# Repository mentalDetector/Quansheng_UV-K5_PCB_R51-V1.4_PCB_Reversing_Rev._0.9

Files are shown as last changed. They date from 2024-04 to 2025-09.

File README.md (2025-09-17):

# Quansheng UV-K5 Hardware Reverse Engineering Project

## Introduction

This project aims to reverse-engineer the hardware design of the Quansheng UV-K5 handheld amateur radio transceiver, specifically focusing on V1.4 of the PCB, which is also used in UV-K5(8) and similar models. The goal was to create a KiCad design that closely resembles the original hardware. Feel free to use this KiCad project to explore more about the mentioned radio or as a starting point for enhancing Quansheng's original design, such as improving RF filtering.

## Thanks!

This project is a community effort, and many people have contributed in various ways (e.g., suggesting make and model of previously unidentified hardware components, component measurements, 3D model creation, reviews, hardware donations, etc.). I particularly want to thank Manuel ([Manuel's GitHub](https://github.com/manujedi)) for donating the PCB and measuring components, and Ludwich ([Ludwich's GitHub](https://github.com/ludwich66)) for thorough documentation (including maintaining the wiki) and improving my initial schematic.

## The Process

Manuel desoldered all components from his PCB after his radio malfunctioned and began measuring them. For components he couldn't measure, he sent them along with his PCB to me.

I measured the remaining components using a nanoVNA, soldering each to a test board to ensure precise measurements.

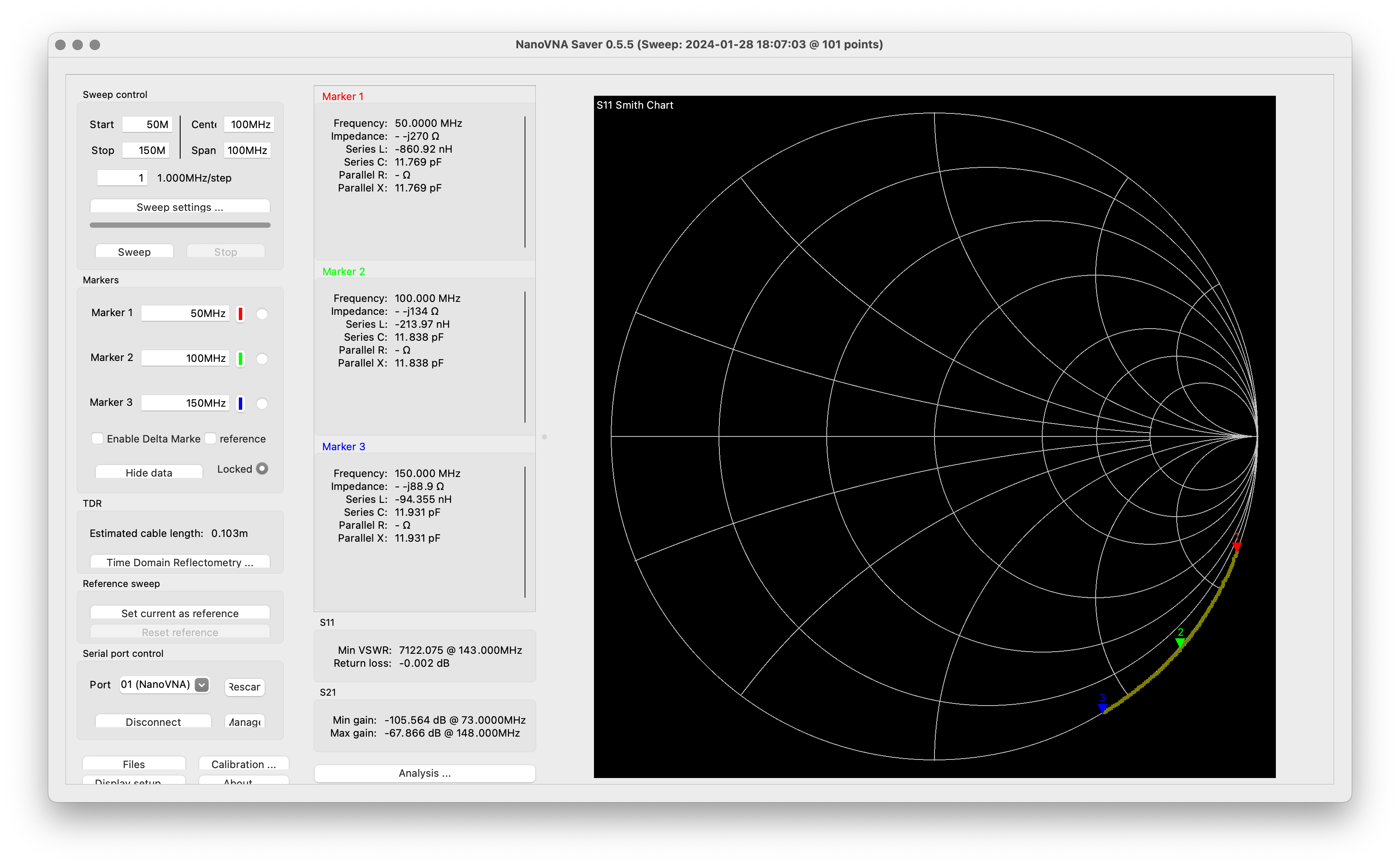
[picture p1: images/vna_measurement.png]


All documentation is available here: [Parts](https://github.com/ludwich66/Quansheng_UV-K5_Wiki/wiki/Parts---Teile). This resource was invaluable during the reverse engineering process.

While we might have encountered measurement errors and may not have chosen the correct component values every time, overall, I believe we've done a decent job. If you spot an error, please inform Ludwich or me.

Afterward, I photographed the PCB to obtain high-resolution images. I also sanded down the PCB to expose the two inner layers, documenting the process here: [PCB Layer Preparation](https://github.com/mentalDetector/Quansheng_UV-K5_PCB_R51-V1.4).

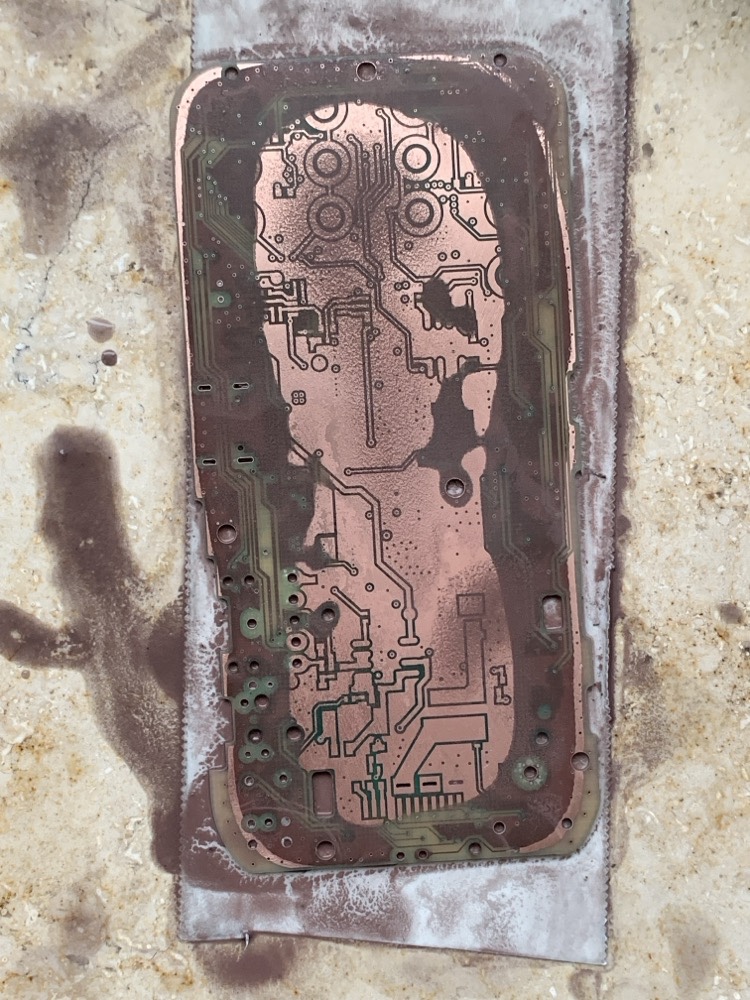
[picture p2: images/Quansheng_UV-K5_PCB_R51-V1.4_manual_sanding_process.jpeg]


I then processed the layer pictures, imported them into the KiCad PCB editor, and aligned everything as accurately as possible. You can still find these pictures in the PCB editor for reference, contributing to the project's size (approximately 60 MB).

Next came the laborious tasks:
- Setting up the PCB view with all PCB borders
- Selecting a random component on the PCB picture
- Placing it onto the schematic
- Switching to the PCB editor and placing the component
- Checking the 3D view of the PCB
- Linking a 3D model for the component if necessary (a time-consuming task)
- Placing additional components
- Connecting the components in the schematics editor
- Switching to the PCB view, updating it
- Running DRC on the schematics and PCB and correcting gating issues

All of my work was completed over a period of about three months, mostly on weekends.

## The Results

<a href="https://github.com/mentalDetector/Quansheng_UV-K5_PCB_R51-V1.4_PCB_Reversing_Rev._0.9/blob/main/images/Quansheng_UV-K5_PCB_R51-V1.4_Rev_0.9_Schematic.pdf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" target="_blank">
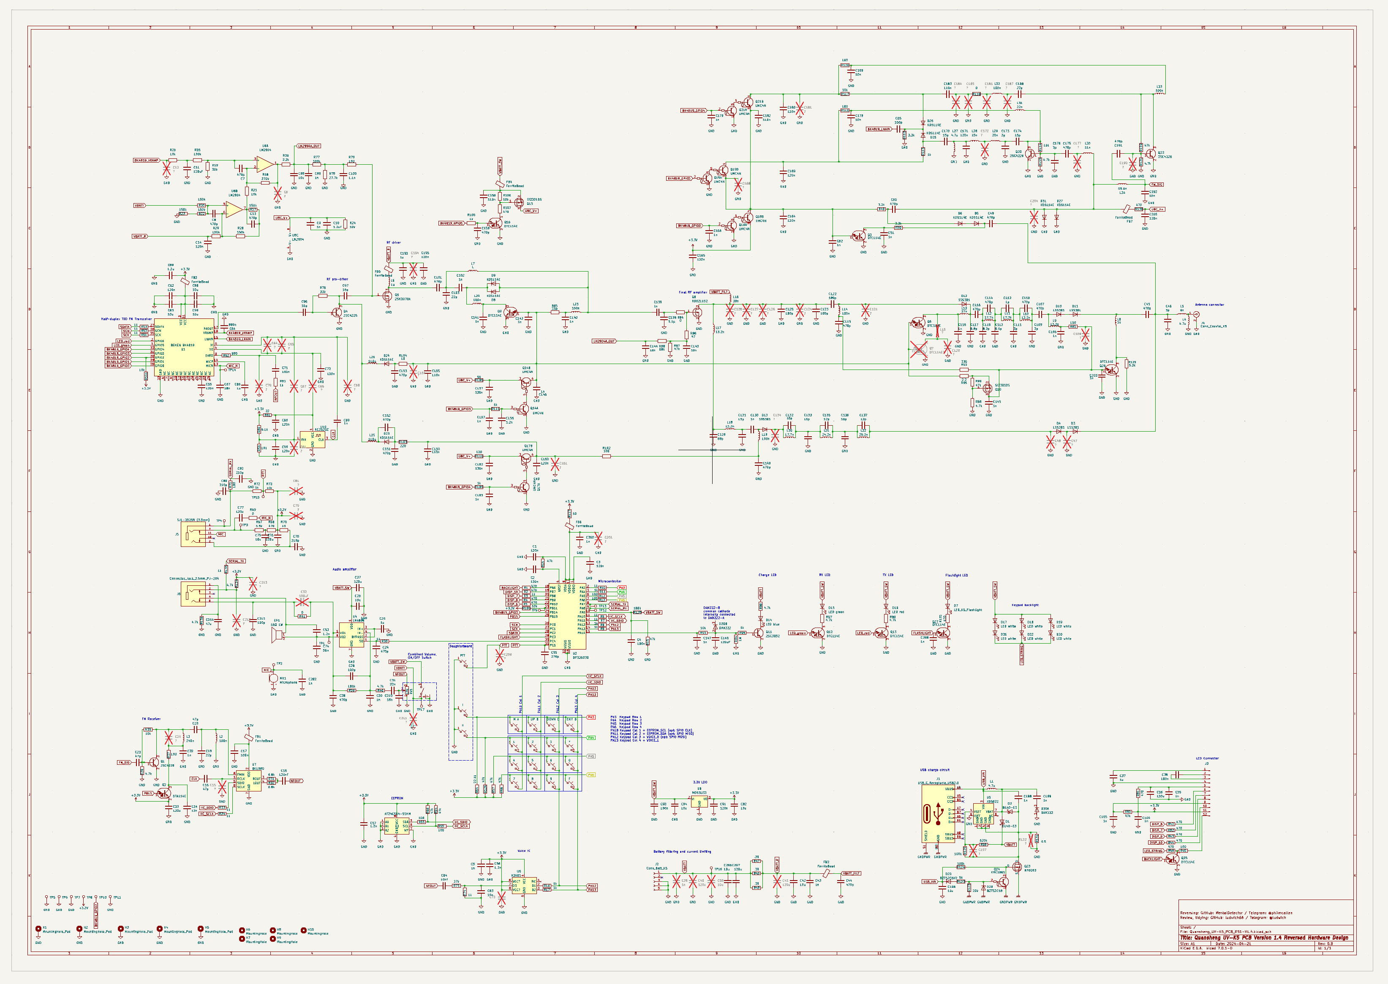
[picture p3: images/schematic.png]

</a>

<a href="https://github.com/mentalDetector/Quansheng_UV-K5_PCB_R51-V1.4_PCB_Reversing_Rev._0.9/blob/main/images/Quansheng_UV-K5_PCB_R51-V1.4_Rev_0.9_Layers.pdf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" target="_blank">
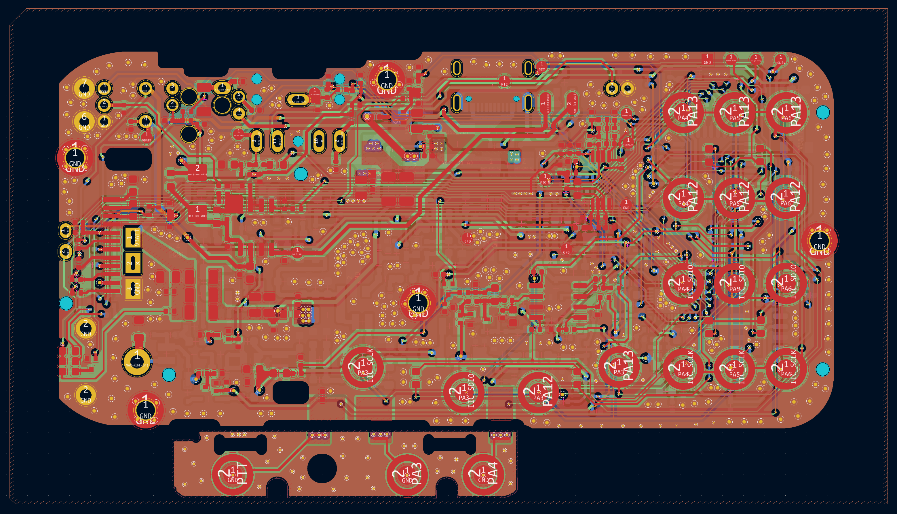
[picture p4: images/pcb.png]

</a>

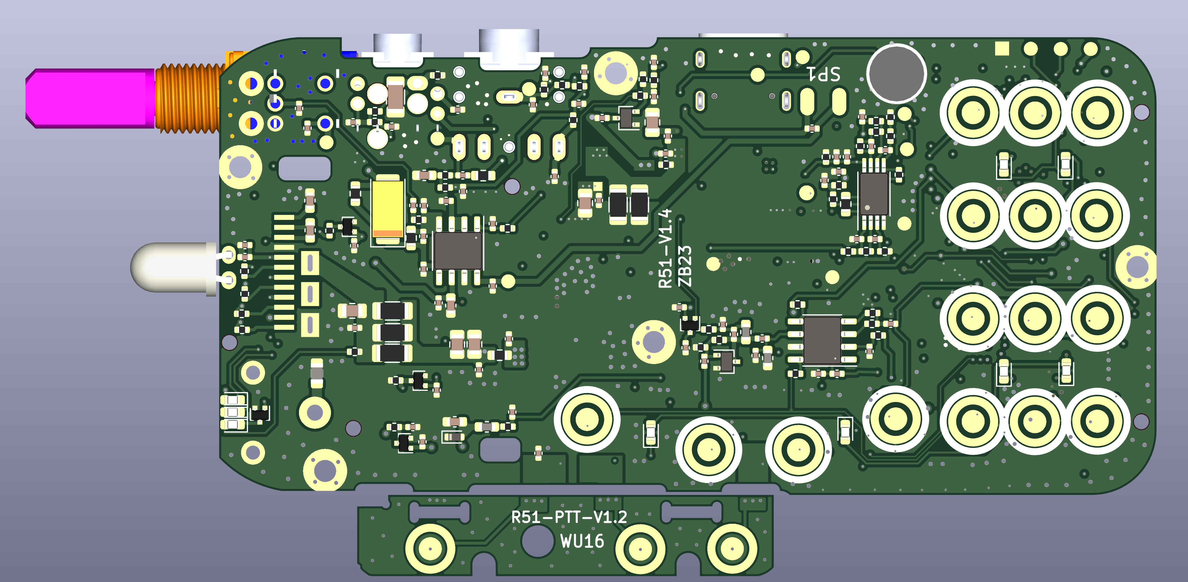
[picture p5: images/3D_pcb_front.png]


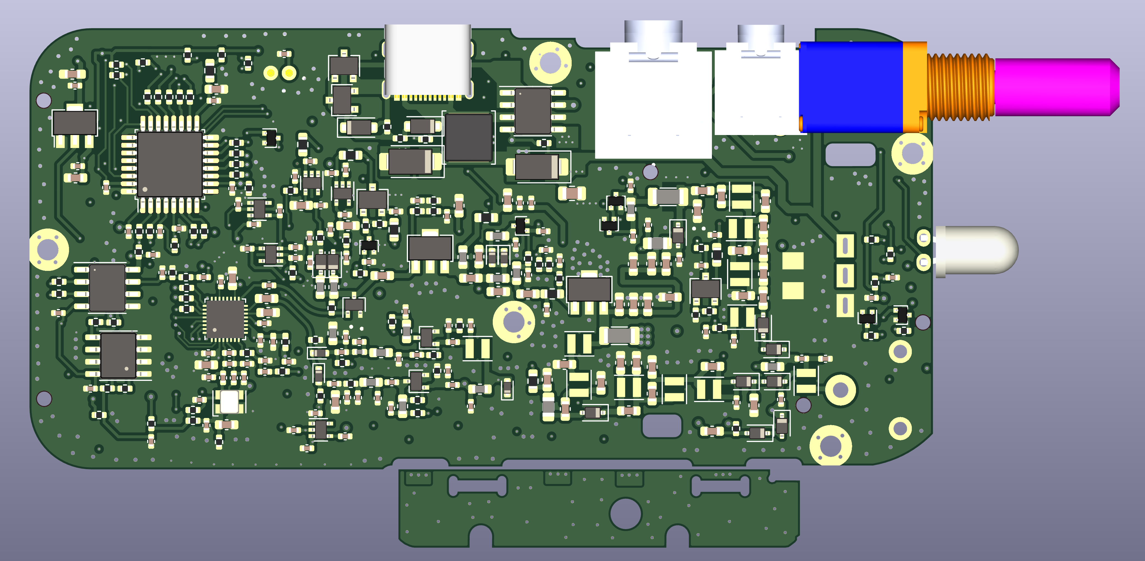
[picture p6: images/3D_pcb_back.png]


## FAQ

**Q: Why is this design labeled as Rev. 0.9?**<br>
A: I'm not completely satisfied with the current schematics' appearance and plan to transition the project to KiCad 8. Consider this a version for public review, and please provide feedback for improvement.

**Q: Why wasn't the project set up in KiCad 8 from the beginning?**<br>
A: KiCad 8 wasn't available when I started the reverse engineering, and I didn't want to switch mid-way.

**Q: The 3D rendering of the PCB is incomplete.**<br>
A: Some components lack proper 3D models or have incorrect ones from similar components, causing them to be missing in the PCB's 3D view. If you have .wrl or .stl files to contribute, please let me know.

**Q: Why are there many errors when I run DRC on the PCB?**<br>
A: This project aims to understand the Quansheng UV-K5 radio's hardware design, not to manufacture PCBs directly. You can't use the PCB files for manufacturing without modifications to meet specific manufacturer rules.

**Q: Some PCB tracks aren't routed correctly on the grid.**<br>
A: Yes, I'm aware. It was a compromise to complete the project in less time. However, all connections should be accurate.

**Q: Why don't the reference designators in this project line up with those in Ludwich's wiki?**<br>
A: I chose not to align them to save time.

## Rev 0.9 Errata

- C192 in the schematics has a wrong value.<br>
Wrong: 10 nF<br>
Correct: 22 pF<br>
See also [Issue #4](https://github.com/mentalDetector/Quansheng_UV-K5_PCB_R51-V1.4_PCB_Reversing_Rev._0.9/issues/4).

- C77 is believed to have a wrong value (needs to be verified). [Issue #3](https://github.com/mentalDetector/Quansheng_UV-K5_PCB_R51-V1.4_PCB_Reversing_Rev._0.9/issues/3)<br>
Wrong: 120 uF<br>
Correct: 100 nF<br>

- A more likely make and model of U10 could be [DSA221SDN/DSB221SDN](https://www.kds.info/product/dsb221sdn-c/?mlang=en). [Issue #2](https://github.com/mentalDetector/Quansheng_UV-K5_PCB_R51-V1.4_PCB_Reversing_Rev._0.9/issues/2)<br>

- C76 is believed to have a wrong value (needs to be verified). [Comment on Issue #3](https://github.com/mentalDetector/Quansheng_UV-K5_PCB_R51-V1.4_PCB_Reversing_Rev._0.9/issues/3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)<br>
Wrong: 120 uF<br>
Correct: 100 nF<br>

- L13 might have an incorrect value in the schematics (needs to be verified). [Comment on Issue #5](https://github.com/mentalDetector/Quansheng_UV-K5_PCB_R51-V1.4_PCB_Reversing_Rev._0.9/issues/5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)<br>

## License

### Hardware
All hardware design files in this repository (e.g. schematics, PCB layouts, BOMs) are licensed under the **CERN Open Hardware Licence v2 - Strongly Reciprocal (CERN-OHL-S)**.  
Full text: see [`CERN-OHL-S-2.0.txt`](./LICENSES/CERN-OHL-S-2.0.txt)

This means, among other things:
- You are free to use, modify, and distribute the hardware.
- Any derivative works **must also be released under CERN-OHL-S**.
- My name must be mentioned as the original author in all redistributions.

### Documentation
All accompanying text, manuals, images, and other documentation are licensed under the **Creative Commons Attribution-ShareAlike 4.0 International (CC BY-SA 4.0)**.  
Full text: see [`CC-BY-SA-4.0.txt`](./LICENSES/CC-BY-SA-4.0.txt)

This means, among other things:
- You are free to use, modify, and distribute the documentation.
- Any derivative works **must also be released under CC BY-SA**.
- My name must be mentioned as the original author in all redistributions.

### Attribution
When redistributing or reusing this project (in whole or in part), please credit it as follows:

Author: mentalDetector<br>
Project: Quansheng UV-K5 Hardware Reverse Engineering Project<br>
Source: [https://github.com/mentalDetector/Quansheng_UV-K5_PCB_R51-V1.4_PCB_Reversing_Rev._0.9](https://github.com/mentalDetector/Quansheng_UV-K5_PCB_R51-V1.4_PCB_Reversing_Rev._0.9)

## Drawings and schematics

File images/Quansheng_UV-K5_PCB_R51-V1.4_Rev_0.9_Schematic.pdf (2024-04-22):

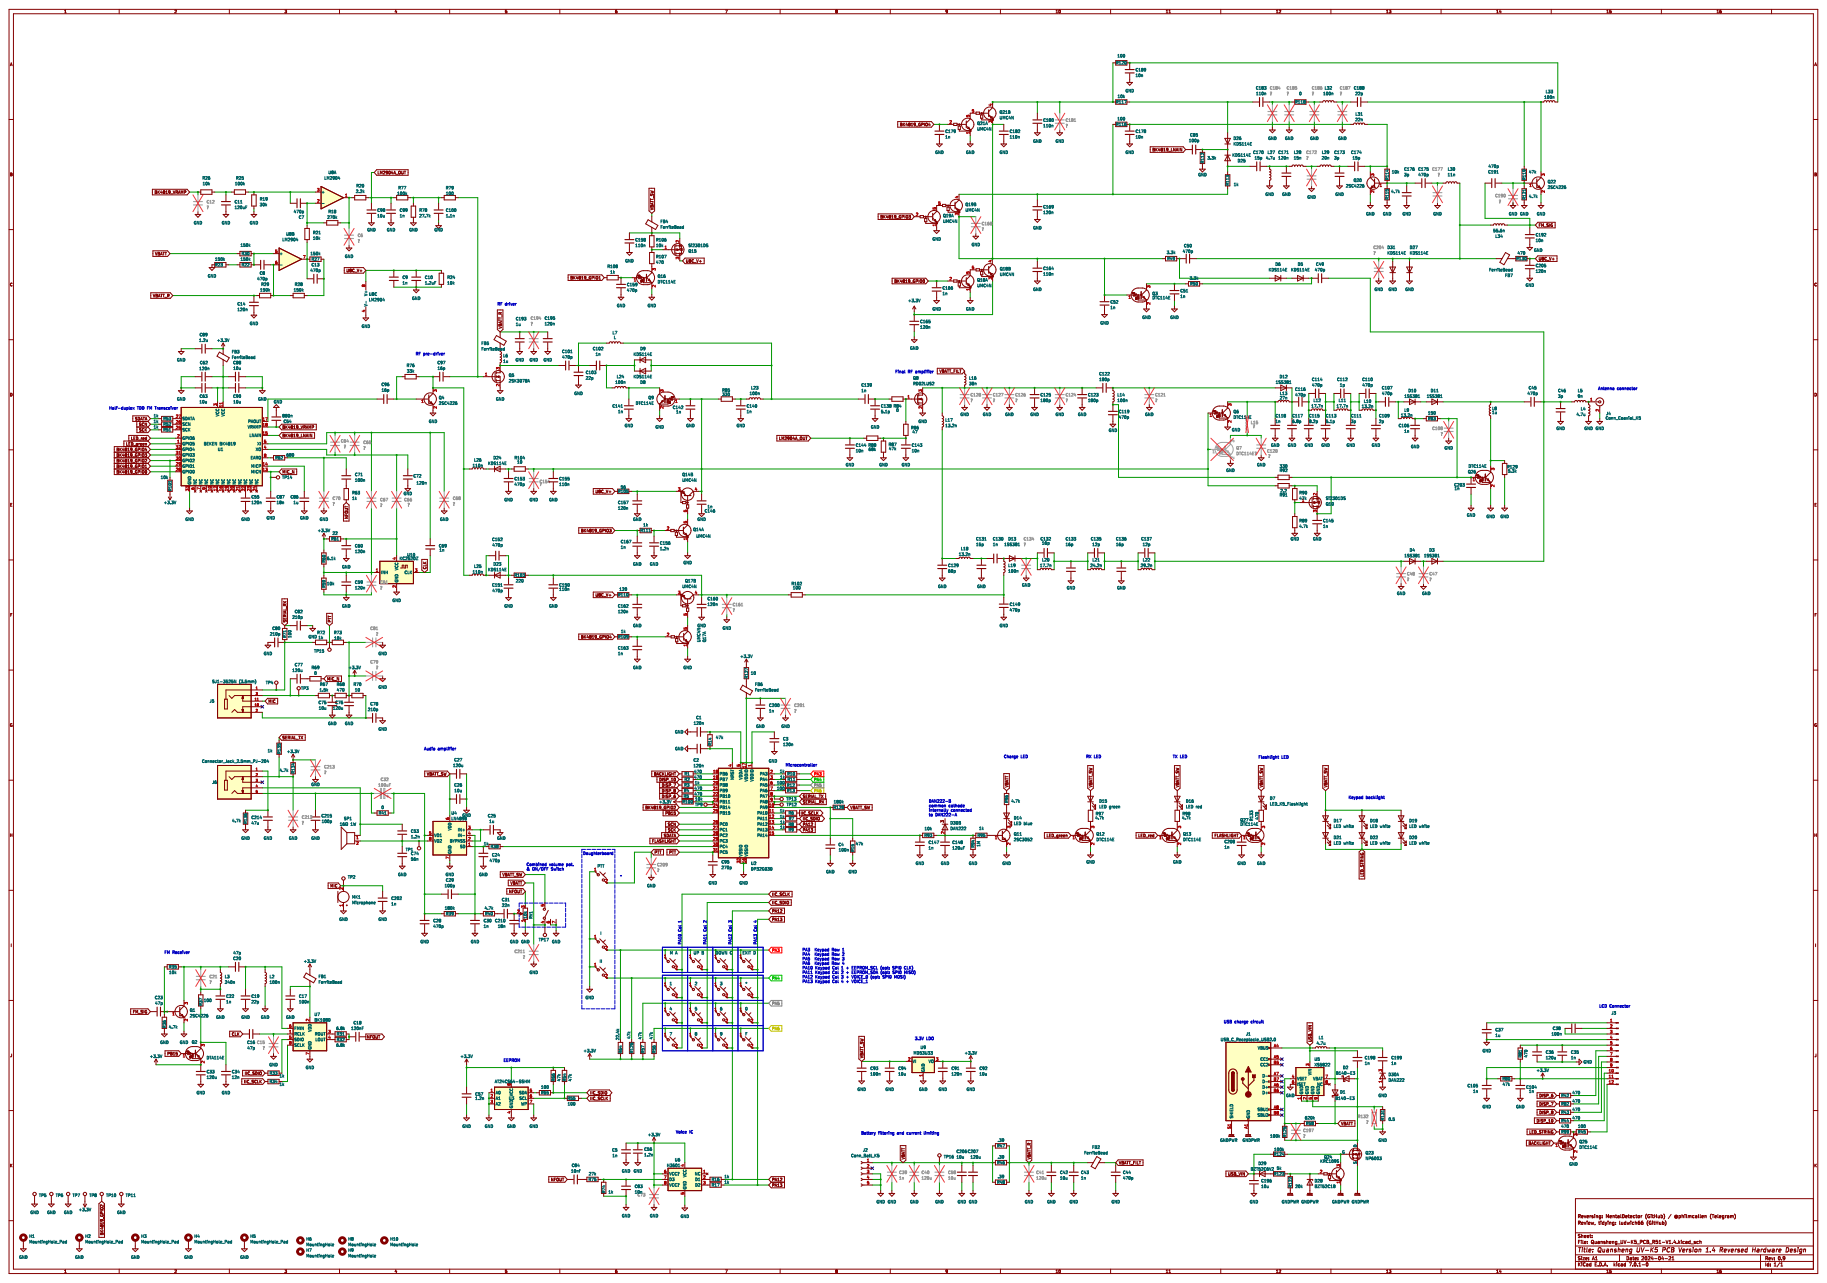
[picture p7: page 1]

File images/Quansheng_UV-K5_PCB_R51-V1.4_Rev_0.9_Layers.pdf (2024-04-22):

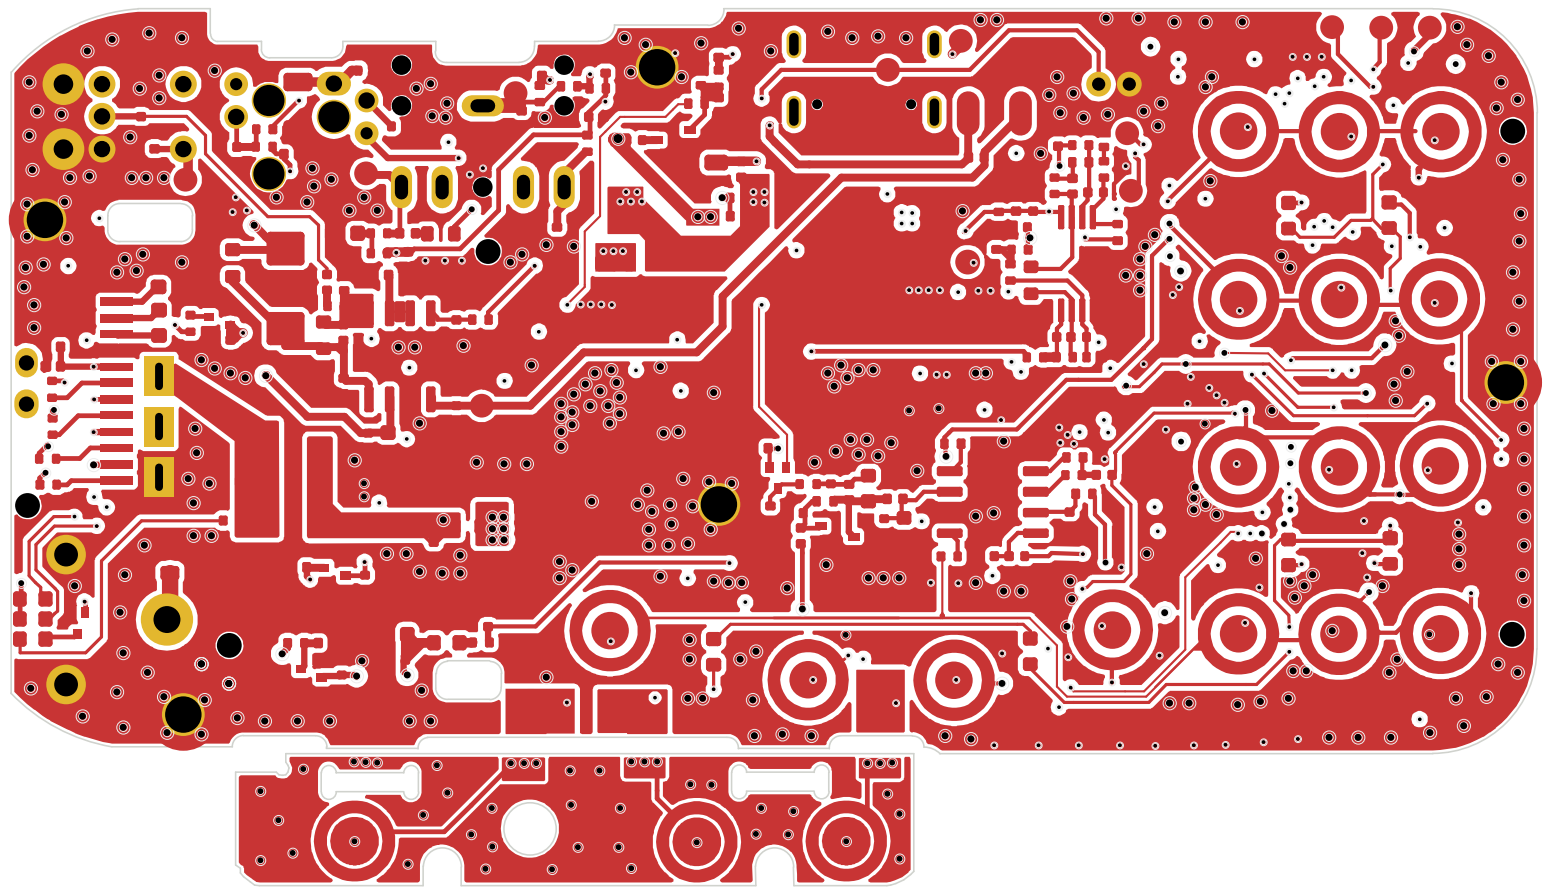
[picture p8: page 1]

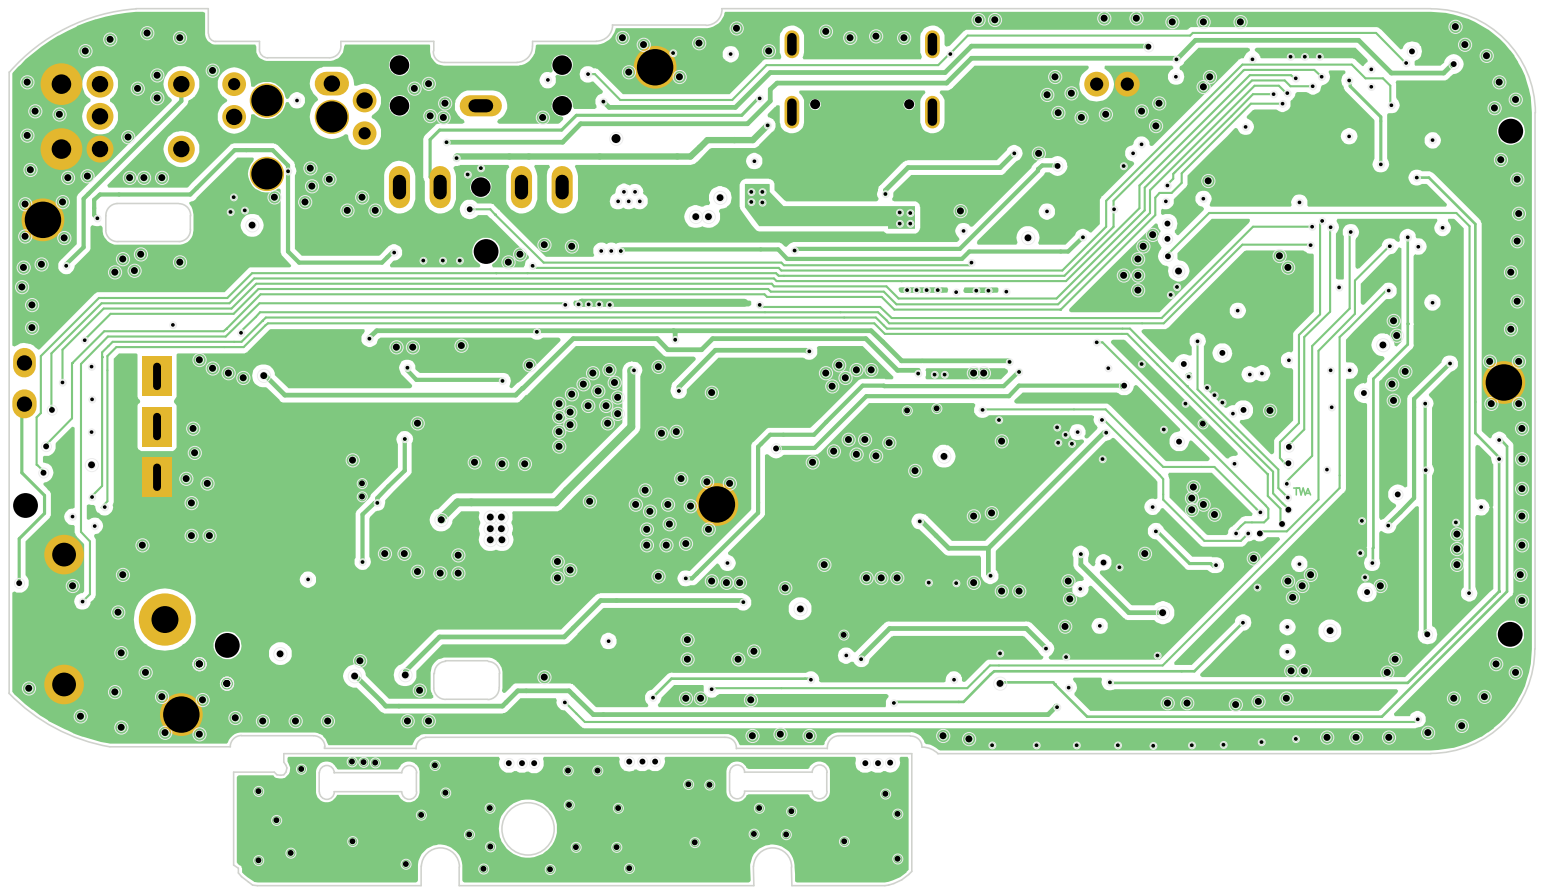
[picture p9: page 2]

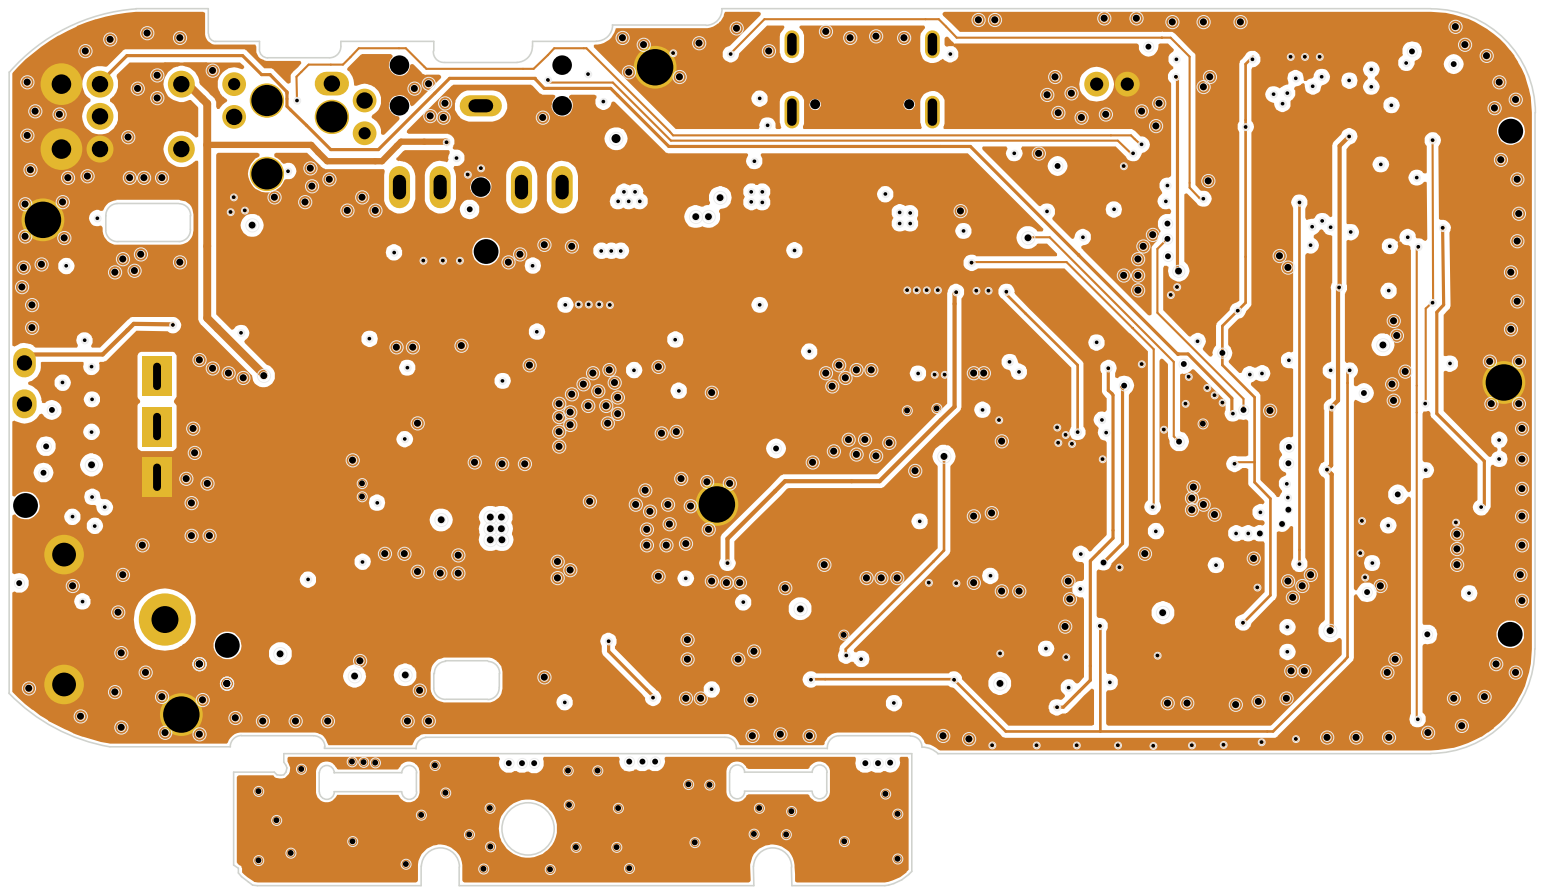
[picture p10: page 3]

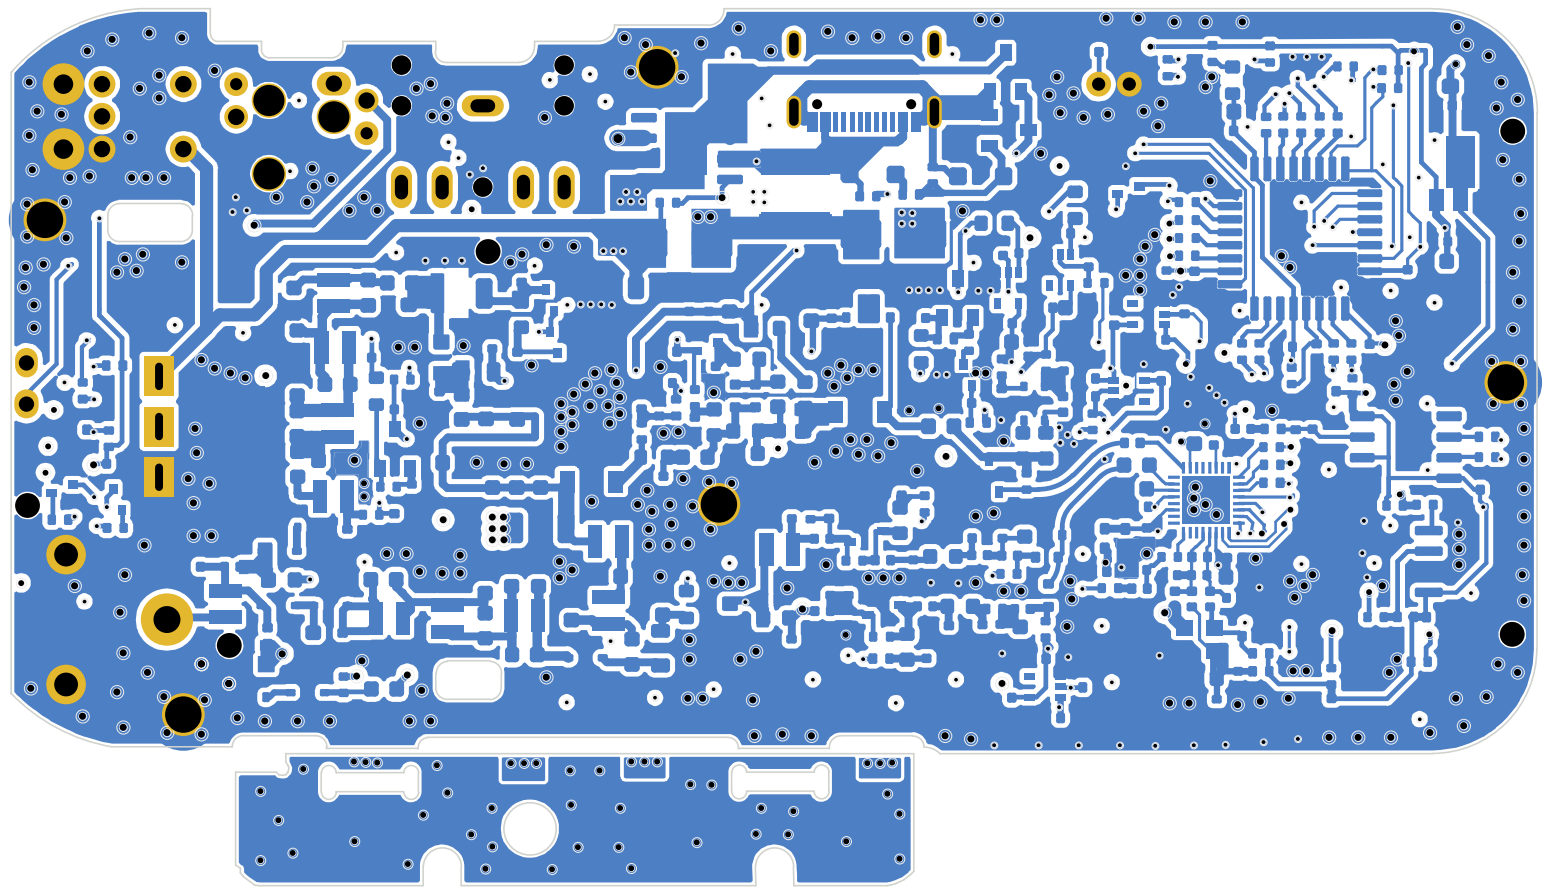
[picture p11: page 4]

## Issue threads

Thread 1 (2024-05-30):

Component parameter

HuXiaoPeng-1, 2024-05-30:
Component parameter：BK1080 > Parameter of FB1 (value)?

HuXiaoPeng-1, 2024-05-30:
![Uploading 1.png…]()

mentalDetector, 2024-06-01:
Unfortunately I cannot view the picture you uploaded.

The value of FB1 is non critical in my opinion. That's why I didn't measure its exact values. It is used to block stray RF from entering the BK1080 power line.

Candidates could be something similar to Coilcraft's DF series (https://www.coilcraft.com/de-de/products/rf/ferrite-core-chip-inductors/0402-(1005)/0402df/0402df-221/).

When I have time during the next weeks, I can try to measure its inductance.

HuXiaoPeng-1, 2024-06-01:
Thank you for the response

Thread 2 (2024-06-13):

BK4819 TCXO

mobilinkd, 2024-06-13:
This is very likely a [KDS DSB221SDN 26.0MHz 0.5ppm TCXO](https://www.kds.info/product/dsb221sdn-c/?mlang=en) judging by the markings. Almost all Chinese radios I have seen use a KDS TCXO for the radio IC. These can be found for [about USD0.50 on AliExpress](https://www.aliexpress.us/item/3256804381169707.html) in small quantities.

mentalDetector, 2024-06-14:
Thanks for noticing. I came across this KDS TCXO during the process, but KiCad didn't have a ready symbol included. I will generate one in the next update and exchange vs. the more likely KDS.

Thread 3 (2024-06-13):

C77 Value is 100nF

mobilinkd, 2024-06-13:
C77 is currently shown as 120uF. This is a 100nF 0402. Let me know if you would prefer PRs rather than filing issues.

mentalDetector, 2024-06-14:
I took this capacitor value out of Ludich's and Manuel's table and did not measure it myself.
120 nF could still be a suitable value for a microphone circuit where only speech frequencies matter, makes sense.
Did you measure the capacitor yourself, and if yes, how?

Creating issues is my preferred option right now, as currently already an updated working version of the schematics is available, but not hosted here yet.

mobilinkd, 2024-06-19:
I removed it and measured it out of circuit using 2 different instruments (Agilent U1252B and LCR Research Pro1 Plus). At least 2 of the caps shown on the schematic as 120nF I removed and measured within 5% of 100nF. 100nF is a much more likely value for these components.

I should mention that I am using a rev 1.5 PCB. The differences are trivial. So far the only notable change I have seen is that they removed R41 and just shorted the pads of C32 on the PCB.

jumbo5566, 2024-10-31:
C76 is 100nF

mentalDetector, 2024-10-31:
Hi jumbo5566, would you mind opening a new issue for that? How did you measure C76? Could well be an error in the schematics.

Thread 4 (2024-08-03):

C192 shows 10n on schematics, could it possibly be 10p?

jeffs555, 2024-08-03:
Was doing spice simulation of the FM and VHF input filtering and the 10n value you show for C192 basically kills the VHF and FM response. Simulation shows a 10n C192 peaks the input signal at about 1MHz and drops the input on two meters by 60db.
Simulation with a 10p C192 shows a reasonable passband for VHF and high HF.

PS Thanks for all the hard work on reverse engineering the schematics.

mentalDetector, 2024-08-03:
Thanks for the nice words. It was a pleasure for me to give something back to the community.

C192 indeed was an error in the schematics which has been pointed out some months ago. I included this in the errata at the bottom of the main page of this project. Initially it showed a correct value of 20pF for the capacitor. After your comment now I checked Ludwich's and my table. This shows that I had measured the value myself with a VNA and found 22pF. I have change the value in the errata now to 22pF.

Please use 22pF for your simulation :-)

If you find further errors, please raise new issues here. If you at one point want to share your simulation file, please let Ludwich or me know.

jeffs555, 2024-08-04:
Thanks for the quick response. I only looked at your PDF schematics, should have looked at the readme too.
Was looking at doing the SI4732 mod and some versions of the mod replace L4 and C23 with higher values. Was just simulating to see what effect they have on the HF response. Would certainly share sim files when I get done.

Closed 2024-08-04.

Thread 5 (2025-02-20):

TX_L13_L15

BH4ME, 2025-02-20:
First of all,thank you for your contribution.

<!-- Failed to upload "微信图片_20250220235001.png" -->

1. L13 maybe is not 27n,i think is 1u~2u like the L8,that is at 400MHz,it isequivalent to impedance 3.k ohm.in order to prevent the signal from flowing through.
2. Q6、Q7、L15,I am not sure what is function is but it looks weird.

BH4ME

mentalDetector, 2025-03-24:
Welcome BH4ME!

1. Thank you for letting me know, I will add this to the possible errata in the readme document here on GitHub. I will check if I have measured this value myself or if it has been measured previously (with possible errors). If you have a chance to measure L13, please let me know. Otherwise I will measure when I get a chance.

2. I think Q6 is there to pull D12 to GND when witching on/off the following filter path for tx/rx (I don't remember which band exactly). Q7 and L15 are note populated in the design. This is probably a leftover from a previous hardware design iteration.
